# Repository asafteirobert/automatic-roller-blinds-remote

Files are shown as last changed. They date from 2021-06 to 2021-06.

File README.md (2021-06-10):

# Automatic roller blinds small remote
A small 30x50x20mm remote with 5 buttons, and an OLED screen. This project is used to control the  [automatic roller blinds motor](https://github.com/asafteirobert/automatic-roller-blinds-motor) project, but you are welcome to adapt the code for yourself; it can be used to control anything with a NRF24L01 module.
Built around an Arduino pro mini.

It has a battery life of a few months.

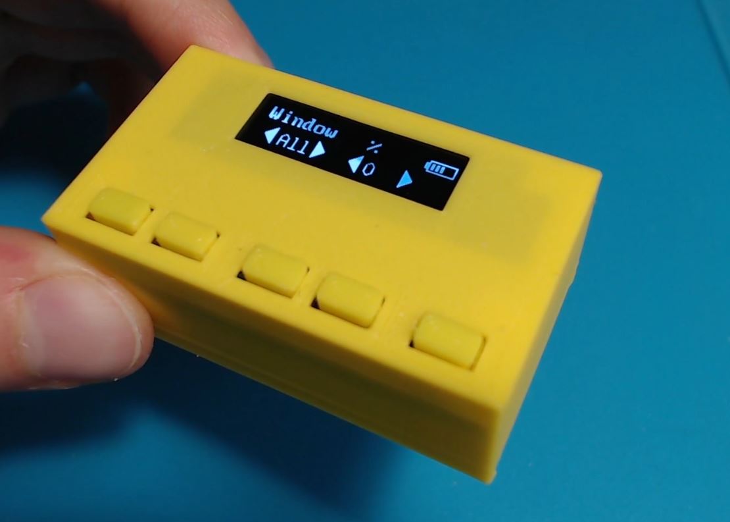
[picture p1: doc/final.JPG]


## How to use it

The remote is used to is used to control the  [automatic roller blinds motor](https://github.com/asafteirobert/automatic-roller-blinds-motor).

The remote will go into deep sleep after 15 seconds. Press any button to wake it up.

First, you will need to connect the remote to your blinds. To do this, hold the last button for 1 second to enter the menu. Select the room number(according to the `ROOM_NUMBER` you defined). Navigate to the "Discover" option. Make sure the remote is close to the blinds and simply press ok. The remote will scan of nearby blinds and remember those which have the same room number.

Next you will need to calibrate the blinds so they know what the maximum and minimum positions are. This can be a bit tedious but should be done carefully as not doing the calibration correctly can damage the blinds. Go to the menu and select "Calibrate". Use buttons 3 and 4 to move the blinds up and down. When the blind is in the top position, press button 1 to save it. When the blind is in the bottom position, press button 2 to save it. Press button 5 to move to the next window and repeat until all windows are calibrated. Now everything is set up and you can use the blinds.

On the main screen you can select the window you want to change, the percentage you want to change it to and, using the last button, confirm the change. An X or ✓  will be displayed depending if the command was sent successfully.

To save a preset, move the blinds to the desired positions, enter the menu, navigate to "Save preset", select the preset number you want to save and press ok. To load a preset, hold the corresponding button while on the main screen (hold the first button to load preset 1, etc).

## Limitations and known issues:
- The range on the NRF24L01 is pretty disappointing when inside a case and covered by a hand. The reliable range is generally limited to one room.
- The remote remembers the last position sent to the blinds and doesn't poll the status. This means that when the blinds are moved (using other remotes, the web interface or RESTful API) the percentage shown on the screen can be out of date.

## Making your own
All the required files are included in this project. This includes source code, 3D files to be 3D printed, schematic and PCB.
For instructions see [doc/assembly.md](doc/assembly.md).

## Project status: Finished, active
All intended functionality is implemented and manually tested. I will try to fix major bugs when they are reported. I will review pull requests, but generally I prefer if you fork the project in order to make your own changes and improvements.

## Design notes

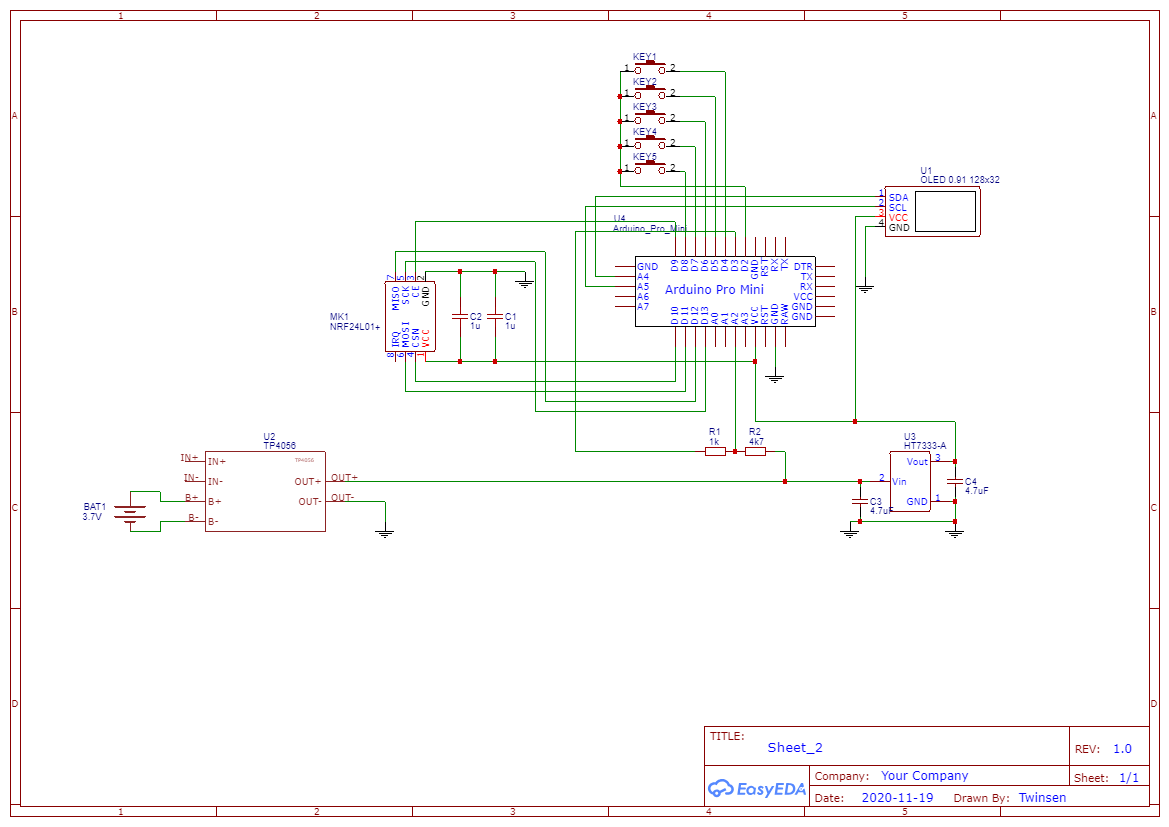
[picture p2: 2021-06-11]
schematic/Schematic_Automatic roller blinds remote discrete regulator_2021-06-11.png

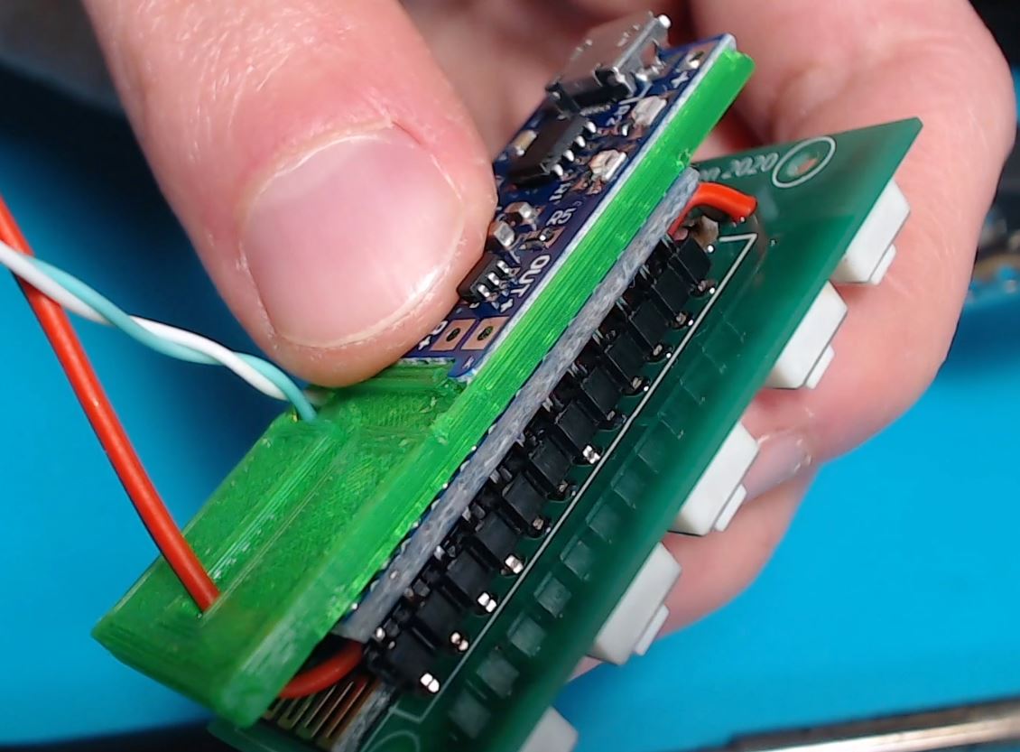
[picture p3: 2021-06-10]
doc/top-part-glued.JPG

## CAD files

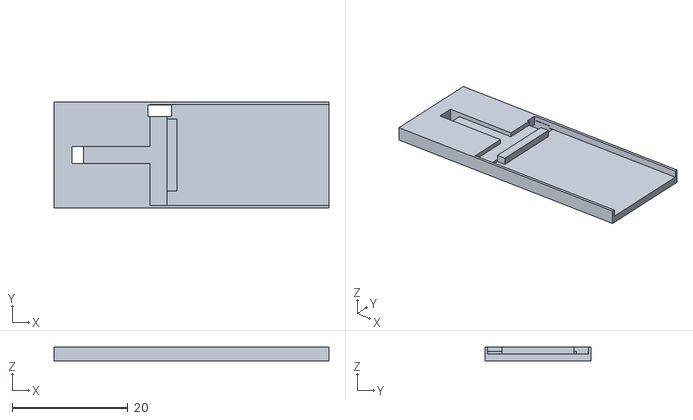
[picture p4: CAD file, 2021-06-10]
3d print/Small Remote Internal Part.stl
47.6 x 18.4 x 2.50

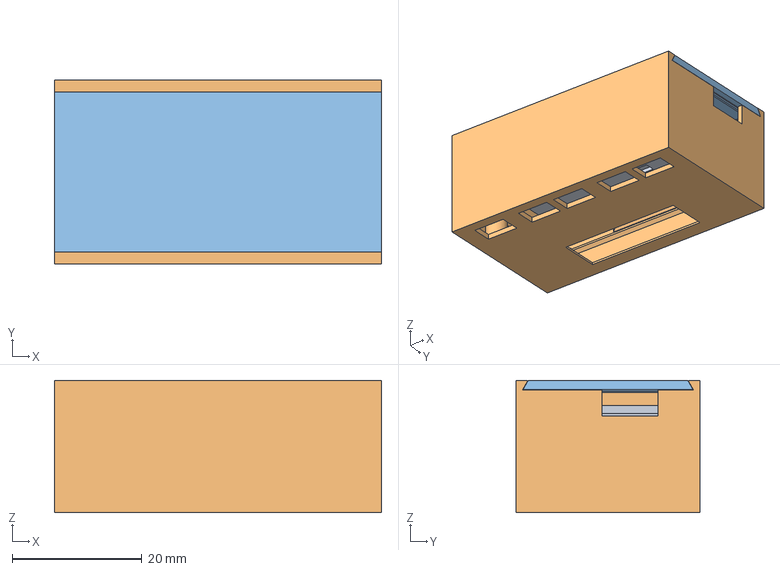
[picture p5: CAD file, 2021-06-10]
3d print/step/Small Remote Case v10.step
50.4 x 28.4 x 20.4 mm

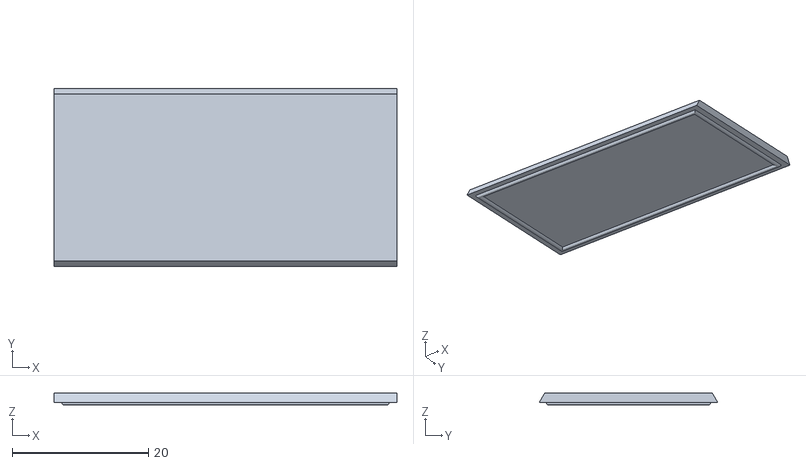
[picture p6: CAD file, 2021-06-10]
3d print/Small Remote Case Lid.stl
50.4 x 26.2 x 1.80

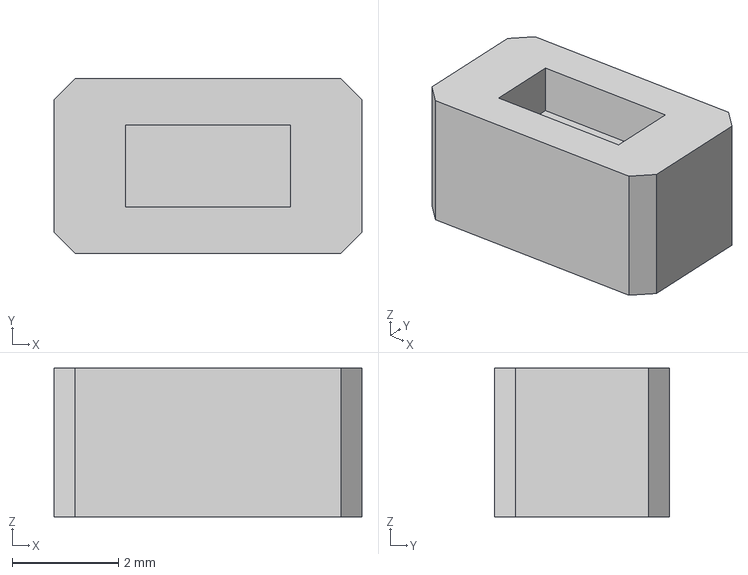
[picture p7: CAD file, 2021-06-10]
3d print/step/Small remote buttons v5.step
5.80 x 3.30 x 2.80 mm

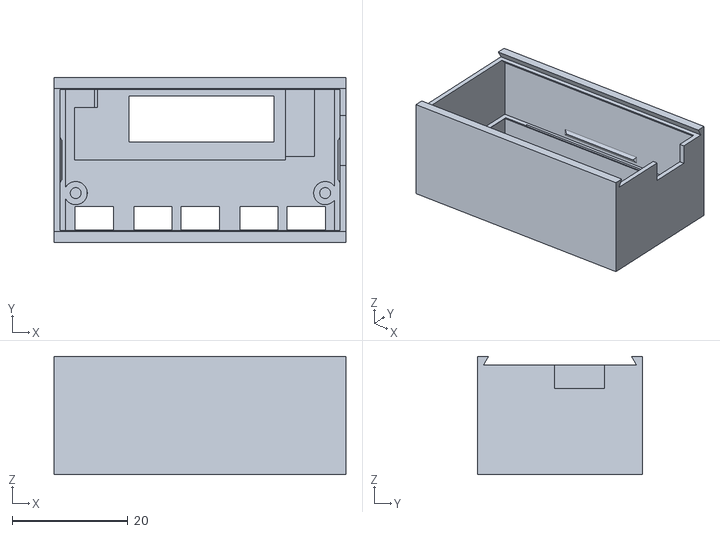
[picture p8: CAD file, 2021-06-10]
3d print/Small Remote Case.stl
50.4 x 28.4 x 20.4

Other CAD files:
3d print/Small Remote button.stl

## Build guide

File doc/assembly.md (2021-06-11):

# Automatic roller blinds small remote assembly instructions

For this project you will need a 3D printer, patience, good soldering skills and some experience with Arduino and Platform IO.

Since I tried to make it cheap, simple, compact and using simple modules, it requires careful assembly.

## Materials
- Arduino Pro Mini 3v3
- 0805 5.1k SMD resistor
- 2x 0805 1uf SMD capacitor
- 2x 0805 4.7uf SMD capacitor
- 5x 3x4x2mm pushbuttons
- NRF24L01+	SMD module
- 1206 1k SMD resistor
- 1206 4k7 SMD resistor
- HT7333 SOT-89 LDO regulator
- OLED 0.91" 128X32 module
- TP4056 battery charging + protection module
- 601148 3.7V 380mAh LiPo battery. Dimensions are 6x11x48mm. [Example link](https://www.aliexpress.com/item/4001065299900.html)
- 3D printed parts found in `3d print` folder. 5x buttons and 1 of the rest.
- PCB
- 2x M2x5 screws

## The circuit board

The PCB needs to be 0.8mm thick(or similar).

You can find the schematic and PCB in the `schematic` folder. It contains an EasyEDA project and Gerber files.

Or simply order the it from this link: https://www.pcbway.com/project/shareproject/Automatic_roller_blinds_small_remote.html

## Steps

1. On the TP4056 charging module, replace R3 with a 5.1k resistor. This will set set the charging current 235mA.
2. Remove R1 and R2 which connect to the LEDs. This will be necessary to connect the wires which will report the charging status to the Arduino.
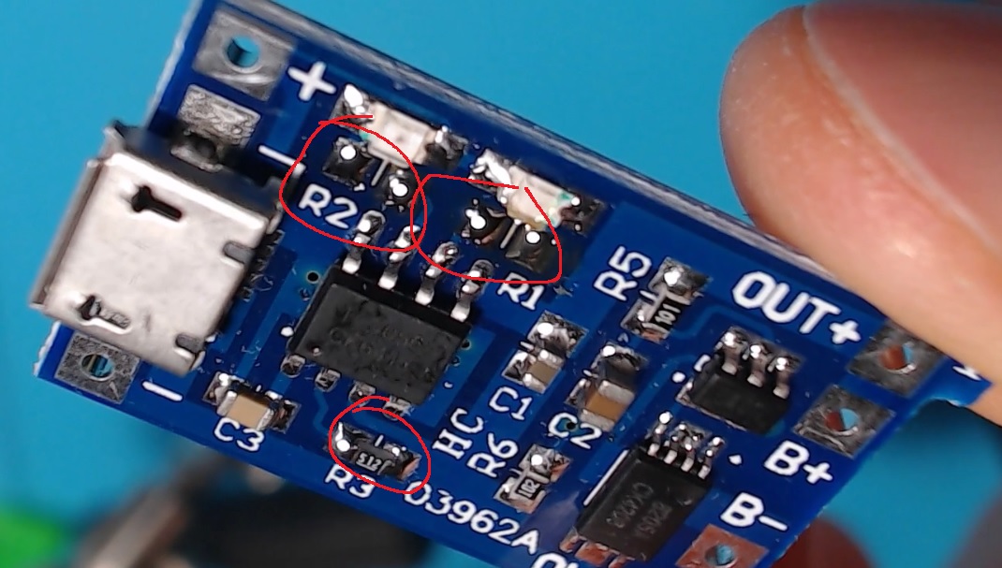
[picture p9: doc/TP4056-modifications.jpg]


3. Remove the regulator and LEDs from the Arduino. This is required for the low power battery operation
4. Remove the switch.
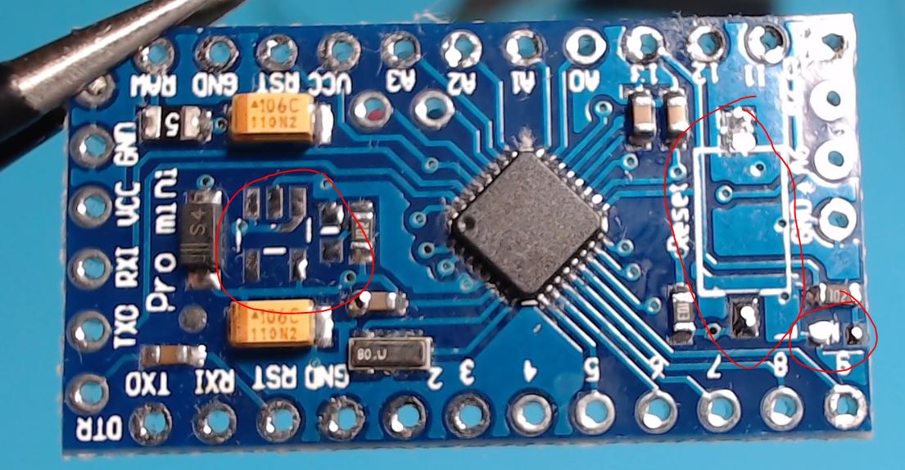
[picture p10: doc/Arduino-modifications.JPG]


5. Open this project in Platform IO, compile and upload it. You will need a USB serial adapter. After assembly it will be difficult to access the programming pins. Alternatively, you can solder a small programming connector.
6. Solder the pin headers to the arduino. Make sure you have the correct number of pins. Make sure the pins are facing the side with the components. Because of the compact design, the pins can't protrude more than 1mm from the bottom side. If necessary, solder from the other side.
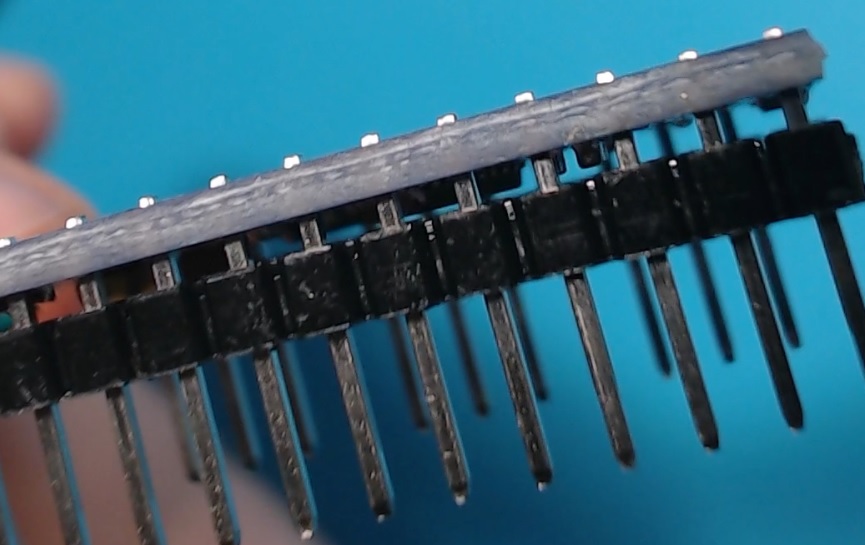
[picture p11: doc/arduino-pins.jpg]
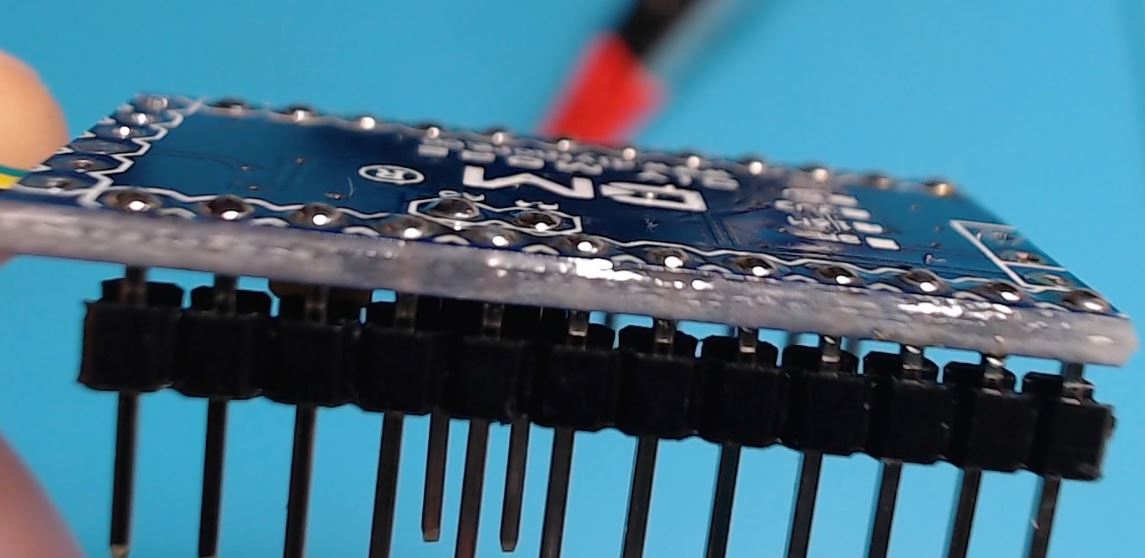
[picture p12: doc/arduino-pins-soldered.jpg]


7. Solder the SMD components to the PCB. Note that the switches are very close to each other. Use double sided tape for the NRF24L01 module to make sure it doesn't touch the nearby pins.
8. Solder the Arduino to the PCB, upside down. Carefully align the Arduino and PCB so both boards are parallel and the distance between the boards is 6.5mm (including the board thickness)
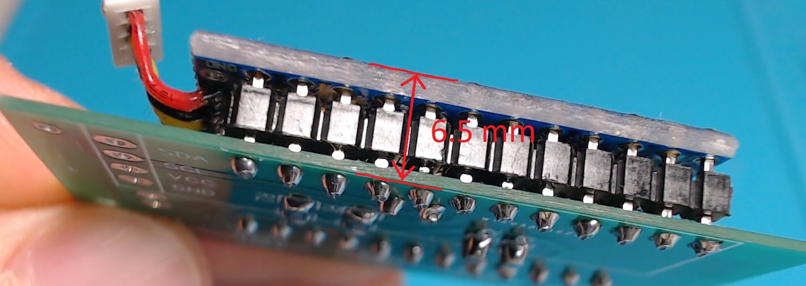
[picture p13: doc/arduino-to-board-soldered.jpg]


9. Solder the OLED module. The spacing is very tight so I added some insulation to make sure these components don't touch. Add a spacer so the screen is secure and parallel to the board.
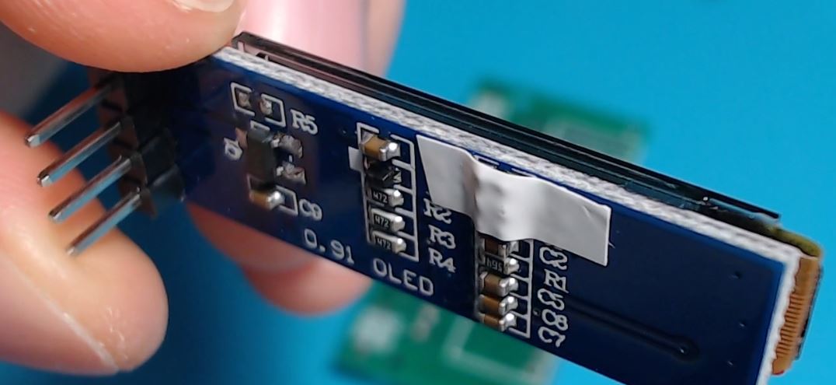
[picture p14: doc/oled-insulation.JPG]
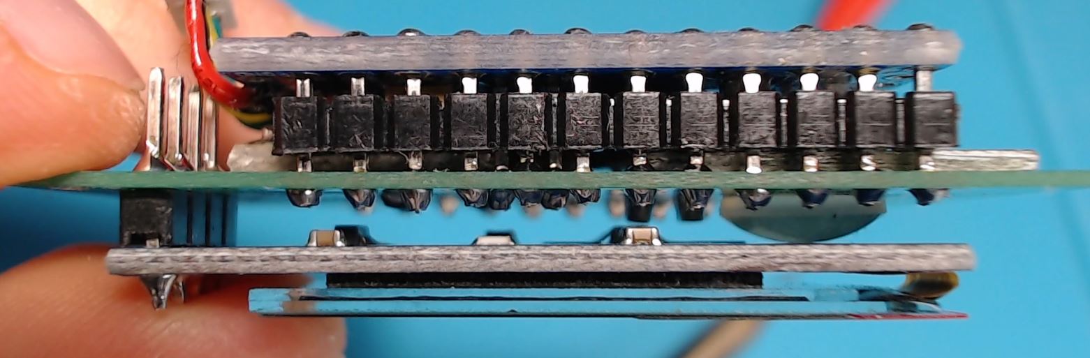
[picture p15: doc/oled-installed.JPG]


10. Solder a pair of wires to the power pins on the board and route them between the 2 boards
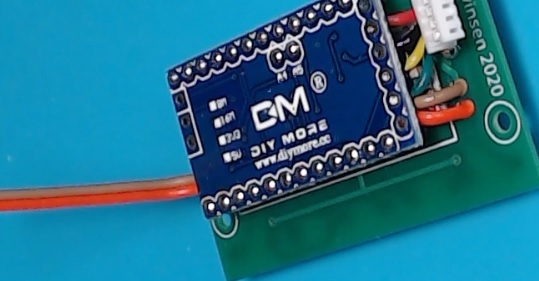
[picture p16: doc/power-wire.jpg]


11. Solder 2 small wires to the A0 and A1 pins of the Arduino. They will be used to read the charge status of the TP4056 charging module.
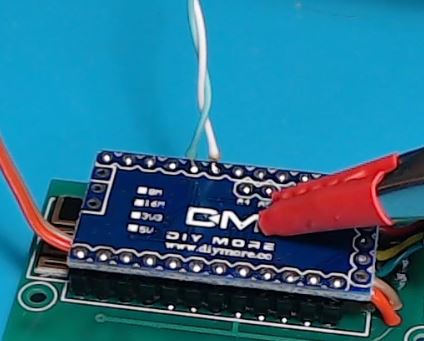
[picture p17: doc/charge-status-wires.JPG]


13. Remove the protective film from the OLED and carefully place the board inside the case. Use M2x6 screws to secure the board.

12. Glue the TP4056 charging module to the "internal part" 3D printed part.
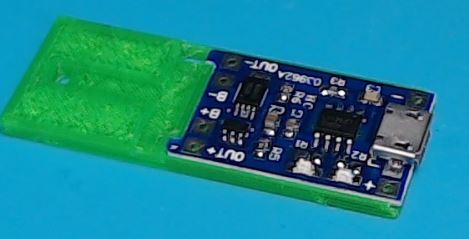
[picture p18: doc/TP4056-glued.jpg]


13. Glue the 3D printed part to the Arduino board. Make sure it's aligned correctly 

14. Solder the power wires to the output of the charging module.

15. Solder the charge status wires to the charging module. A0 is connected to the R2 pad coming from the IC, A1 is connected to the R1 pad coming from the IC.
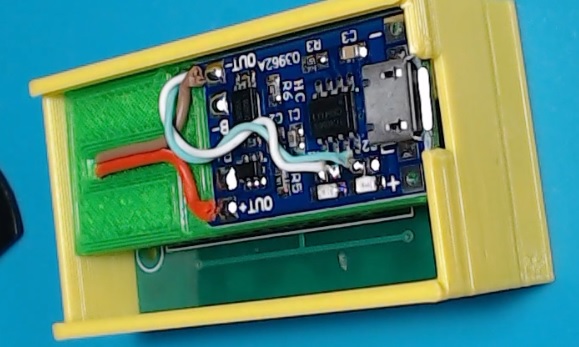
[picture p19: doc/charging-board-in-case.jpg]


16. Install and solder the battery.
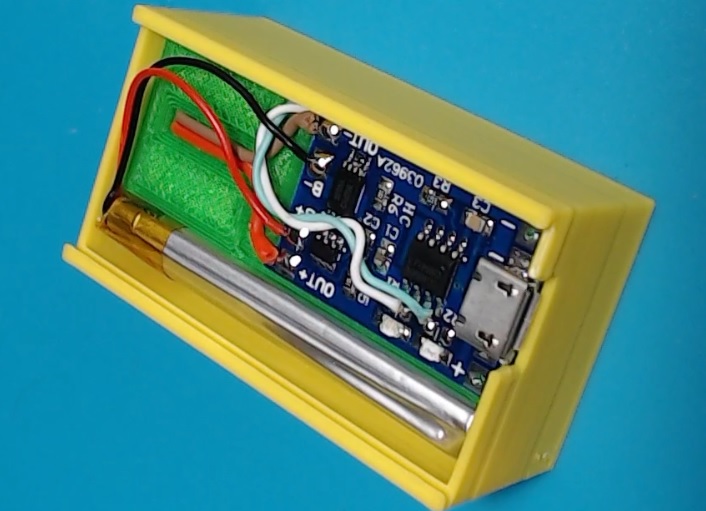
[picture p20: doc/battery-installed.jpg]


18. Test that it works.
17. Close the cover, glue the cover if necessary, glue the 3D printed buttons.


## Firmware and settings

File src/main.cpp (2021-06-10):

#include <Arduino.h>
#include "Constants.h"
#include "Util.h"
#include "BlindsData.h"
#include "Settings.h"
#include <U8g2lib.h>
#include <LowPower.h>
#include <RF24.h>
#include <AceButton.h>
using namespace ace_button;

//#define DEBUG

#ifdef DEBUG
#define DEBUG_PRINT(x)  Serial.println (x)
#include "printf.h"
#else
#define DEBUG_PRINT(x)
#endif

struct ReturnDataType
{
  uint8_t roomId;
  uint8_t blindId;
  int8_t currentTargetPercent;
};

//Special values written in targetPercent for various commands
static constexpr int8_t TARGET_DISCOVER = -1; //does nothing, just send the latest ack packet
static constexpr int8_t TARGET_SET_START = -2;
static constexpr int8_t TARGET_SET_END = -3;
static constexpr int8_t TARGET_MOVE_BACK = -4;
static constexpr int8_t TARGET_MOVE_FWD = -5;
struct SentDataType
{
  int8_t targetPercent;
  uint8_t speed;
};

BlindsData blindsData;
Settings settings;
uint8_t currentSetting = 0;

uint8_t lastButtonPressed = 0;
bool charging = false;
bool chargingDone = false;
unsigned long lastActivity = 0;
//volatile bool wokeUp = false;

//Button related
AceButton button1(PINS_BUTTONS[0], HIGH, 1);
AceButton button2(PINS_BUTTONS[1], HIGH, 2);
AceButton button3(PINS_BUTTONS[2], HIGH, 3);
AceButton button4(PINS_BUTTONS[3], HIGH, 4);
AceButton button5(PINS_BUTTONS[4], HIGH, 5);

void handleButtons(AceButton*, uint8_t, uint8_t);

//Display related
U8G2_SSD1306_128X32_UNIVISION_F_HW_I2C u8g2(U8G2_R0, U8X8_PIN_NONE);

enum class ScreenState
{
  Home,
  Settings,
  Discover,
  Calibrate
};

ScreenState screenState = ScreenState::Home;
int8_t selectedPercent = 0;
uint8_t presetToSave = 1;

bool updateDisplay = true;
char displayBuffer[20];
bool batteryBlink = false;
unsigned long lastBatteryBlink = 0;
unsigned long lastScreenUpdate = 0;
unsigned long lastPresetSaveTime = 0;
unsigned long lastPresetLoadTime = 0;
uint8_t lastLoadedPreset = 0;
unsigned long lastTransmissionTime = 0;
uint8_t lastTransmissionState = 0; //0=empty 1=ok 2=fail

uint8_t discoveryFoundTotal = 0;

float batteryLevel = -1;
unsigned long lastBatteryRead = 0;

// RF24 related
RF24 radio(PIN_NRF_CE, PIN_NRF_CS);


void drawBatteryLevel()
{
  if ((millis() - lastBatteryRead) > 5000 || batteryLevel == -1)
    batteryLevel = calculateBatteryLevel(batteryVoltage(), REMOTE_BATTERY_TYPE);

  // Position on OLED
  int x = 108; int y = 4;
  if (batteryLevel > 1)
  {
    u8g2.drawFrame(x + 2, y, 18, 9);
    u8g2.drawBox(x, y + 2, 2, 5);

    byte bars = truncf(batteryLevel / (100.0 / 6));
    for (int i = 0; (i < 5 && i < bars); i++)
      u8g2.drawBox(x + 4 + (3 * i), y + 2, 2, 5);
  }
  else
  {
    if (batteryBlink == true)
    {
      u8g2.drawFrame(x + 2, y, 18, 9);
      u8g2.drawBox(x, y + 2, 2, 5);
    }
  }
}

void drawStartScreen()
{
  u8g2.clearBuffer();

#ifndef DEBUG
  u8g2.drawXBMP(0, 4, 24, 24, ICON_LOGO);
#endif

  u8g2.setFont(u8g2_font_7x14_tr);
  u8g2.setCursor(30, 18);
  u8g2.print(F("Remote v1.0"));
#ifdef DEBUG
  u8g2.setCursor(91, 32);
  u8g2.print(F("DEBUG"));
#endif

  u8g2.sendBuffer();
  delay(500);
}

void drawSignalTransmitting()
{
  u8g2.drawXBMP(114, 18, 12, 12, ICON_SIGNAL_TRANSMITTING);
  u8g2.sendBuffer();
}

void drawSignalTransmitOk()
{
  u8g2.drawXBMP(114, 18, 12, 12, ICON_SIGNAL_TRANSMIT_OK);
  u8g2.sendBuffer();
}

void drawSignalTransmitFail()
{
  u8g2.drawXBMP(114, 18, 12, 12, ICON_SIGNAL_TRANSMIT_FAIL);
  u8g2.sendBuffer();
}

void drawClearSignal()
{
  u8g2.setDrawColor(0);
  u8g2.drawBox(114, 18, 12, 12);
  u8g2.setDrawColor(1);
  u8g2.sendBuffer();
}

void drawDiscoveryStatus(uint8_t percent, uint8_t foundUseful, uint8_t foundTotal, bool drawOk = false)
{
  u8g2.clearBuffer();
  u8g2.drawXBMP(0, 3, 8, 8, ICON_DISCOVER);
  u8g2.setFont(u8g2_font_pxplusibmvga8_tr);
  u8g2.setCursor(11, 12);
  u8g2.print(String(F("Searching ")) + String(percent) + String("%"));
  u8g2.setFont(u8g2_font_7x14_tr);
  u8g2.setCursor(10, 30);
  u8g2.print(String(F("Found ")) + String(foundUseful) + String("/") + String(foundTotal));

  if (drawOk)
  {
    u8g2.setCursor(100, 30);
    u8g2.print(F("[OK]"));
  }
  u8g2.sendBuffer();
}

void updateMainDisplay()
{
  unsigned long currentMillis = millis();
  if (currentMillis - lastScreenUpdate > 1000)
  {
    lastScreenUpdate = currentMillis;
    updateDisplay = true;
  }
  
  if ((batteryLevel <= 1) && currentMillis - lastBatteryBlink > 500)
  {
    batteryBlink = !batteryBlink;
    lastBatteryBlink = currentMillis;
    updateDisplay = true;
  }

  if (!updateDisplay)
    return;
  updateDisplay = false;

  u8g2.clearBuffer();

  if (screenState == ScreenState::Home)
  {
    if (blindsData.blindsCount == 0)
    {
      u8g2.setFont(u8g2_font_pxplusibmvga8_tr);
      u8g2.setCursor(0, 12);
      u8g2.print(F("No blinds"));
      u8g2.setFont(u8g2_font_7x14_tr);
      u8g2.setCursor(0, 30);
      u8g2.print(F("Use discover"));
    }
    else if (currentMillis - lastPresetLoadTime < 1000 && lastLoadedPreset != 0)
    {
      u8g2.setFont(u8g2_font_pxplusibmvga8_tr);
      u8g2.setCursor(0, 12);
      u8g2.print(F("Loaded"));
      u8g2.setFont(u8g2_font_7x14_tr);
      u8g2.setCursor(0, 30);
      u8g2.print(String(F("Preset ")) + String(lastLoadedPreset));
    }
    else
    {
      lastLoadedPreset = 0; //clear lastLoadedPreset so the message is not repeated on millis() overflow
      u8g2.setFont(u8g2_font_pxplusibmvga8_tr);
      u8g2.setCursor(0, 12);
      u8g2.print(F("Window"));

      u8g2.setCursor(70, 12);
      u8g2.print(F("%"));
      
      u8g2.setFont(u8g2_font_open_iconic_arrow_2x_t);
      u8g2.setCursor(0, 32);
      u8g2.drawGlyph(0, 32, 77);
      u8g2.drawGlyph(36, 32, 78);

      u8g2.drawGlyph(59, 32, 77);
      u8g2.drawGlyph(95, 32, 78);

      u8g2.setFont(u8g2_font_7x14_tr);
      u8g2.setCursor(16, 30);
      if (blindsData.selectedBlind == 0)
        u8g2.print(F("All"));
      else
        u8g2.print(blindsData.blinds[blindsData.selectedBlind-1].blindId);

      u8g2.setCursor(75, 30);
      if (blindsData.getSelectedBlindPercent() != selectedPercent)
        u8g2.setFont(u8g2_font_7x14B_tr);
      u8g2.print(selectedPercent);
    }

    drawBatteryLevel(); 

    if (charging)
    {
      u8g2.drawXBMP(96, 2, 12, 12, ICON_CHARGING);
    }
    if (chargingDone)
    {
      u8g2.drawXBMP(98, 2, 8, 12, ICON_CHARGING_DONE);
    }

    if (currentMillis - lastTransmissionTime < 1000 && lastTransmissionState != 0)
    {
      if (lastTransmissionState == 1)
        drawSignalTransmitOk();
      else
        drawSignalTransmitFail();
    }
    else
      lastTransmissionState = 0; //clear lastTransmissionState so the icon is not repeated on millis() overflow

  }
  else if (screenState == ScreenState::Settings)
  {
    //Draw setting name
    u8g2.drawXBMP(0, 3, 8, 8, ICON_SETTINGS);
    u8g2.setFont(u8g2_font_pxplusibmvga8_tr);
    u8g2.setCursor(11, 12);
    if (currentSetting < SETTINGS_COUNT)
      u8g2.print(settings.getSettingString(currentSetting));
    if (currentSetting == SETTINGS_COUNT)
      u8g2.print(F("Discover"));
    if (currentSetting == SETTINGS_COUNT + 1)
      u8g2.print(F("Calibrate"));
    if (currentSetting == SETTINGS_COUNT + 2)
      u8g2.print(F("Exit"));

    //Draw arrows
    if (currentSetting < SETTINGS_COUNT)
    {
      u8g2.setFont(u8g2_font_open_iconic_arrow_2x_t);
      u8g2.drawGlyph(39, 32, 77);
      u8g2.drawGlyph(75, 32, 78);
    }

    u8g2.setFont(u8g2_font_7x14_tr);

    //Draw setting value
    u8g2.setCursor(55, 30);
    if (currentSetting < SETTINGS_COUNT)
      u8g2.print(settings.getSettingValueString(currentSetting));

    if (currentSetting == SETTINGS_COUNT - 1 && currentMillis - lastPresetSaveTime < 1000)
    {
      u8g2.setCursor(92, 30);
      u8g2.print(F("Saved"));
    }
    else
    {
      //Draw OK for relevant settings
      u8g2.setCursor(100, 30);
      if (currentSetting >= SETTINGS_COUNT - 1)
      {
        u8g2.print(F("[OK]"));
      }
    }
    
  }
  else if (screenState == ScreenState::Discover)
  {
    drawDiscoveryStatus(100, blindsData.blindsCount, discoveryFoundTotal, true);
  }
  else if (screenState == ScreenState::Calibrate)
  {
    u8g2.drawXBMP(0, 3, 8, 8, ICON_CALIBRATE);
    u8g2.setFont(u8g2_font_pxplusibmvga8_tr);
    u8g2.setCursor(10, 12);
    u8g2.print(String(F("Calibrating ")) + String(blindsData.blinds[blindsData.selectedBlind-1].blindId));
    u8g2.setFont(u8g2_font_open_iconic_play_2x_t);
    u8g2.drawGlyph(0, 32, 73);
    u8g2.drawGlyph(25, 32, 74);
    u8g2.setFont(u8g2_font_open_iconic_arrow_2x_t);
    u8g2.drawGlyph(50, 32, 77);
    u8g2.drawGlyph(75, 32, 78);
    
    u8g2.setFont(u8g2_font_7x14_tr);
    u8g2.setCursor(100, 30);
    u8g2.print(F("[OK]"));
  }
  u8g2.sendBuffer();
}

void setupButtonsCommon()
{
  pinMode(PIN_BUTTONS_COMMON, INPUT_PULLUP);

  for (int i = 0; i < BUTTONS_COUNT; i++)
  {
    pinMode(PINS_BUTTONS[i], OUTPUT);
    digitalWrite(PINS_BUTTONS[i], LOW);
  }
}

void setupButtonsDistinct()
{
  pinMode(PIN_BUTTONS_COMMON, OUTPUT);
  digitalWrite(PIN_BUTTONS_COMMON, LOW);

  for (int i = 0; i < BUTTONS_COUNT; i++)
  {
    pinMode(PINS_BUTTONS[i], INPUT_PULLUP);
  }
}

void wakeUpHandler()
{
  //don't do anything here. See https://github.com/rocketscream/Low-Power/issues/89
}

void wakeUp()
{
  setupButtonsDistinct();
  u8g2.setPowerSave(false);
  radio.powerUp();
  delay(5);
  //wokeUp = false;
  lastActivity = millis();

  //wait around 5ms for all buttons to be unpressed so that no event is registered after the wakeup
  uint8_t noInputLoops = 0;
  while (true)
  {
    if (!button1.isPressedRaw() &&
        !button2.isPressedRaw() &&
        !button3.isPressedRaw() &&
        !button4.isPressedRaw() &&
        !button5.isPressedRaw())
      noInputLoops++;
    if (noInputLoops > 5)
      break;
    delay(1);
  }
}

void goToSleep()
{
  radio.stopListening();
  radio.powerDown();
  u8g2.setPowerSave(true);

  //wait around 5ms for all buttons to be unpressed so that we don't get stuck in sleep
  uint8_t noInputLoops = 0;
  while (true)
  {
    if (!button1.isPressedRaw() &&
        !button2.isPressedRaw() &&
        !button3.isPressedRaw() &&
        !button4.isPressedRaw() &&
        !button5.isPressedRaw())
      noInputLoops++;
    if (noInputLoops > 5)
      break;
    delay(1);
  }

  setupButtonsCommon();
  delay(5);
  //wokeUp = false;
  attachInterrupt(digitalPinToInterrupt(PIN_BUTTONS_COMMON), wakeUpHandler, LOW);
  LowPower.powerDown(SLEEP_FOREVER, ADC_OFF, BOD_OFF); 
  detachInterrupt(digitalPinToInterrupt(PIN_BUTTONS_COMMON));
  wakeUp();
}

void setup()
{
#ifdef DEBUG
  Serial.begin(9600);
#endif
  DEBUG_PRINT(F("Starting..."));
  settings.loadFromEEPROM();
  blindsData.loadFromEEPROM();

  //high-z so we don't waste power
  pinMode(PIN_BATTERY_MEASURE_GROUND, INPUT);

  //set reference to INTERNAL for battery measurement
  analogReference(INTERNAL);
  analogRead(PIN_BATTERY_MEASURE);

  setupButtonsDistinct();
  pinMode(PIN_CHARGING, INPUT_PULLUP);
  pinMode(PIN_CHARGING_DONE, INPUT_PULLUP);

  ButtonConfig* buttonConfig = ButtonConfig::getSystemButtonConfig();
  buttonConfig->resetFeatures();
  buttonConfig->setEventHandler(handleButtons);
  buttonConfig->setClickDelay(900);
  buttonConfig->setLongPressDelay(1000);
  buttonConfig->setRepeatPressInterval(100);
  buttonConfig->setFeature(ButtonConfig::kFeatureClick);
  buttonConfig->setFeature(ButtonConfig::kFeatureLongPress);
  buttonConfig->setFeature(ButtonConfig::kFeatureRepeatPress);
 
  //u8g2.setDisplayRotation(U8G2_R2);
  u8g2.begin();
  u8g2.setContrast(settings.displayContrast*25.5);

  drawStartScreen();
  // Start radio communication
  radio.begin();
  radio.setChannel(NRF_CHANNEL);
  radio.setPALevel(RF24_PA_MAX);
  radio.setDataRate(RF24_250KBPS);
  radio.enableAckPayload();
  radio.enableDynamicPayloads();
  radio.setRetries(5, 15);
  radio.openWritingPipe(NRF_PIPE);
  radio.stopListening();
#ifdef DEBUG
  printf_begin();
  radio.printDetails();
#endif
}

//discovery runs by it's self and doesn't use the program loop
void runDiscovery()
{
  drawDiscoveryStatus(0, 0, 0);
  uint8_t sendingPipe[5];
  for(uint8_t i = 1; i<5; i++)
    sendingPipe[i] = NRF_PIPE[i];
  sendingPipe[1] = settings.roomId;
  blindsData.resetToDefault();
  discoveryFoundTotal = 0;
  //loop through all ids and remember who responded
  for (uint8_t currentId = 1; currentId<=BlindsData::MAX_BLIND_COUNT; currentId++)
  {
    sendingPipe[0] = currentId;
    radio.openWritingPipe(sendingPipe);

    SentDataType sentData;
    sentData.targetPercent = TARGET_DISCOVER;
    sentData.speed = settings.speed;
    bool sendSuccess = radio.write(&sentData, sizeof(sentData));

    ReturnDataType returnedData;
    while (radio.isAckPayloadAvailable())
    {
      uint8_t len = radio.getDynamicPayloadSize();
      if (len == sizeof(returnedData))
      {
        radio.read(&returnedData, sizeof(returnedData));
        if (sendSuccess)
        {
          discoveryFoundTotal++;
          if (settings.roomId == 0 || returnedData.roomId == settings.roomId)
          {
            blindsData.blinds[blindsData.blindsCount].currentTargetPercent = returnedData.currentTargetPercent;
            blindsData.blinds[blindsData.blindsCount].blindId = returnedData.blindId;
            blindsData.blindsCount++;
          }
        }
      }
      else
      {
        radio.flush_rx();
        delay(2);
      }
    }
    drawDiscoveryStatus(uint8_t((double(currentId)/BlindsData::MAX_BLIND_COUNT)*100), blindsData.blindsCount, discoveryFoundTotal);
    lastActivity = millis();
  }
  blindsData.saveToEEPROM();
  updateDisplay = true;
}

bool sendSpecialCommand(int8_t command, uint8_t speed = 0)
{
  if (blindsData.selectedBlind == 0)
    return false;
  uint8_t sendingPipe[5];
  for(uint8_t i = 1; i<5; i++)
    sendingPipe[i] = NRF_PIPE[i];

  sendingPipe[0] = blindsData.blinds[blindsData.selectedBlind-1].blindId;
  sendingPipe[1] = settings.roomId;
  radio.openWritingPipe(sendingPipe);

  SentDataType sentData;
  sentData.targetPercent = command;
  if (speed == 0)
    sentData.speed = settings.speed;
  else
    sentData.speed = speed;
  bool sendSuccess = radio.write(&sentData, sizeof(sentData));

  ReturnDataType returnedData;
  while (radio.isAckPayloadAvailable())
  {
    uint8_t len = radio.getDynamicPayloadSize();
    DEBUG_PRINT("Got ack payload len:" + String(len));
    if (len == sizeof(returnedData))
    {
      radio.read(&returnedData, sizeof(returnedData));
      //returned data contains the previous status but it's the best we have
      blindsData.blinds[blindsData.selectedBlind-1].currentTargetPercent = selectedPercent;
    }
    else
    {
      radio.flush_rx();
      delay(2);
      DEBUG_PRINT("Discarded bad packet <<<");
    }
  }
  if (sendSuccess == true)
  {
    DEBUG_PRINT(F("Transmission success"));
  }
  else
  {
    DEBUG_PRINT(F("Failed transmission"));
  }
  return sendSuccess;
}

bool sendSelectedPositionUpdate(bool resendCurentState = false)
{
  if (blindsData.blindsCount == 0)
    return true;
  drawSignalTransmitting();
  bool result = true;

  uint8_t sendingPipe[5];
  for(uint8_t i = 1; i<5; i++)
    sendingPipe[i] = NRF_PIPE[i];
  sendingPipe[1] = settings.roomId;
  //loop to send to all. If a particular blind is selected, it will only loop once.
  for (uint8_t currentSendingBlind = 0; currentSendingBlind<blindsData.blindsCount; currentSendingBlind++)
  {
    if (blindsData.selectedBlind != 0)
      currentSendingBlind = blindsData.selectedBlind-1;
    sendingPipe[0] = blindsData.blinds[currentSendingBlind].blindId;
    radio.openWritingPipe(sendingPipe);

    SentDataType sentData;
    sentData.targetPercent = resendCurentState?blindsData.blinds[currentSendingBlind].currentTargetPercent:selectedPercent;
    sentData.speed = settings.speed;
    bool sendSuccess = radio.write(&sentData, sizeof(sentData));

    ReturnDataType returnedData;
    while (radio.isAckPayloadAvailable())
    {
      uint8_t len = radio.getDynamicPayloadSize();
      DEBUG_PRINT("Got ack payload len:" + String(len));
      if (len == sizeof(returnedData))
      {
        radio.read(&returnedData, sizeof(returnedData));
        //returned data contains the previous status so we don't do anything with it
        blindsData.blinds[currentSendingBlind].currentTargetPercent = sentData.targetPercent;
      }
      else
      {
        radio.flush_rx();
        delay(2);
        DEBUG_PRINT("Discarded bad packet <<<");
      }
    }
    if (sendSuccess == true)
    {
      DEBUG_PRINT(F("Transmission success"));
    }
    else
    {
      DEBUG_PRINT(F("Failed transmission"));
    }
    result = result && sendSuccess;
    if (blindsData.selectedBlind != 0)
      break;
  }
  updateDisplay = true;
  lastTransmissionTime = millis();
  if (result)
    lastTransmissionState = 1;
  else
    lastTransmissionState = 2;
  return result;
}

void settingsChanged()
{
  if (currentSetting == 2)
    u8g2.setContrast(uint8_t(settings.displayContrast*25.5));
}
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
void loop()
{
  //if (wokeUp)
  //  wakeUp();

  button1.check();
  button2.check();
  button3.check();
  button4.check();
  button5.check();
 
  charging = !digitalRead(PIN_CHARGING);
  chargingDone = !digitalRead(PIN_CHARGING_DONE);

  if (charging || chargingDone)
    lastActivity = millis();

  updateMainDisplay();

  if ((millis() - lastActivity) > 15000)
    goToSleep();
}

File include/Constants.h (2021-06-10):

#ifndef _CONSTANTS_h
#define _CONSTANTS_h
#include "arduino.h"

// ======= Pin defination =======
const uint8_t PIN_BATTERY_MEASURE = A2;
const uint8_t PIN_BATTERY_MEASURE_GROUND = 3;
const uint8_t PIN_RANDOM_SEED = A6; //unconnected pin to give us some random noise
const uint8_t PIN_NRF_CE = 9;
const uint8_t PIN_NRF_CS = 10;
const uint8_t PIN_BUTTONS_COMMON = 2;
const uint8_t PINS_BUTTONS[] = {4,5,6,7,8};
const uint8_t BUTTONS_COUNT = 5;
const uint8_t PIN_CHARGING = A0;
const uint8_t PIN_CHARGING_DONE = A1;

// ======= NRF =======
const static uint8_t NRF_PIPE[5] = {0x01, 0x01, 0x0e, 0xf1, 0xbf};//first byte is blind id, second byte is room id
const static uint8_t NRF_CHANNEL = 103;

// ======= Battery monitoring =======
const float REMOTE_BATTERY_SENSOR_REF_VOLTAGE = 1.089;
const float REMOTE_BATTERY_SENSOR_MULTIPLIER = 5.7;
const byte REMOTE_BATTERY_TYPE = 0; //0 Lipo, 1 Li-ion

//Typical cell voltage to percentage table for lipo and liion
const byte BATTERY_LEVEL_TABLE_COUNT = 23;
const static float BATTERY_LEVEL_VOLTAGE[BATTERY_LEVEL_TABLE_COUNT] PROGMEM =    { 3.1, 3.15, 3.2, 3.25, 3.3, 3.35, 3.4, 3.45, 3.5, 3.55, 3.6, 3.65, 3.7, 3.75, 3.8, 3.85, 3.9, 3.95, 4,  4.05, 4.1, 4.15, 4.2 };
const static byte BATTERY_LEVEL_PERCENT[2][BATTERY_LEVEL_TABLE_COUNT] PROGMEM = {{ 0,   0,    0,   0,    0,   0,    1,   2,    3,   4,    6,   9,    13,  23,   33,  48,   59,  69,   77, 84,   90,  96,   100 },
                                                                                 { 0,   0,    0,   0,    1,   2,    3,   4,    6,   8,    13,  21,   33,  49,   59,  68,   75,  83,   88, 95,   98,  99,   100 }};


// ======= Icons =======
const static uint8_t ICON_LOGO[] PROGMEM =
{
  0x00, 0x00, 0x00, 0x00, 0x00, 0x00, 0x00, 0x7e, 0x00, 0x80, 0x3c, 0x01,
  0xe0, 0x00, 0x07, 0x70, 0x18, 0x0e, 0x30, 0x18, 0x0c, 0x98, 0x99, 0x19,
  0x80, 0xff, 0x01, 0x04, 0xc3, 0x20, 0x0c, 0x99, 0x30, 0xec, 0xa5, 0x37,
  0xec, 0xa5, 0x37, 0x0c, 0x99, 0x30, 0x04, 0xc3, 0x20, 0x80, 0xff, 0x01,
  0x98, 0x99, 0x19, 0x30, 0x18, 0x0c, 0x70, 0x18, 0x0e, 0xe0, 0x00, 0x07,
  0x80, 0x3c, 0x01, 0x00, 0x7e, 0x00, 0x00, 0x00, 0x00, 0x00, 0x00, 0x00
};

const static uint8_t ICON_SIGNAL_TRANSMITTING[] PROGMEM =
{
  0x18, 0x00, 0x0c, 0x00, 0xc6, 0x00, 0x66, 0x00, 0x23, 0x06, 0x33, 0x0f,
  0x33, 0x0f, 0x23, 0x06, 0x66, 0x00, 0xc6, 0x00, 0x0c, 0x00, 0x18, 0x00
};

const static uint8_t ICON_SIGNAL_CONNECTED[] PROGMEM =
{
  0x18, 0x00, 0x0c, 0x00, 0xc6, 0x00, 0x66, 0x00, 0x23, 0x06, 0x33, 0x09,
  0x33, 0x09, 0x23, 0x06, 0x66, 0x00, 0xc6, 0x00, 0x0c, 0x00, 0x18, 0x00
};

const static uint8_t ICON_SIGNAL_NOCONNECTION[] PROGMEM =
{
  0x00, 0x00, 0x00, 0x00, 0x00, 0x00, 0x00, 0x00, 0x00, 0x06, 0x00, 0x09,
  0x00, 0x09, 0x00, 0x06, 0x00, 0x00, 0x00, 0x00, 0x00, 0x00, 0x00, 0x00
};

const static uint8_t ICON_SIGNAL_TRANSMIT_OK[] PROGMEM = //12x12
{
   0x00, 0x0c, 0x00, 0x0e, 0x00, 0x0f, 0x80, 0x0f, 0xc3, 0x07, 0xe7, 0x03,
   0xff, 0x01, 0xfe, 0x00, 0x7c, 0x00, 0x38, 0x00, 0x10, 0x00, 0x00, 0x00 };

const static uint8_t ICON_SIGNAL_TRANSMIT_FAIL[] PROGMEM = //12x12
{
   0x00, 0x00, 0x00, 0x00, 0x0c, 0x03, 0x9c, 0x03, 0xf8, 0x01, 0xf0, 0x00,
   0xf0, 0x00, 0xf8, 0x01, 0x9c, 0x03, 0x0c, 0x03, 0x00, 0x00, 0x00, 0x00 
}; 

const static uint8_t ICON_CHARGING[] PROGMEM = //12x12
{
   0x00, 0x00, 0x80, 0x00, 0x40, 0x00, 0x60, 0x00, 0x30, 0x00, 0xf0, 0x01,
   0xf8, 0x00, 0xc0, 0x00, 0x60, 0x00, 0x20, 0x00, 0x10, 0x00, 0x00, 0x00
};

const static uint8_t ICON_CHARGING_DONE[] PROGMEM = //8x12
{
   0x00, 0x00, 0x00, 0x40, 0xe0, 0x72, 0x3f, 0x1e, 0x0c, 0x00, 0x00, 0x00 
};

const static uint8_t ICON_SETTINGS[] PROGMEM = //8x8
{
   0x18, 0x7e, 0x7e, 0xe7, 0xe7, 0x7e, 0x7e, 0x18
}; 


const static uint8_t ICON_DISCOVER[] PROGMEM = //8x8
{
   0x0e, 0x18, 0x26, 0x58, 0xd6, 0xac, 0xab, 0x03
}; 


const static uint8_t ICON_CALIBRATE[] PROGMEM = //8x8
{
   0x08, 0x1c, 0x3e, 0x08, 0x08, 0x3e, 0x1c, 0x08
}; 

#endif

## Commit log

2021-06-10 Initial project commit
    [Small Remote Case Lid.stl, Small Remote Case v10.step, Small Remote Case.stl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]
2021-06-10 Fixed images in assembly.md
2021-06-11 Added PCB order link
2021-06-11 Added schematic image
